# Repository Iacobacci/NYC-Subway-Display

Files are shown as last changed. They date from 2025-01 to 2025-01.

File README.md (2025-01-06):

# NYC Subway Time LED Matrix Display
## Overview

This project was derived from https://github.com/techytobias/NYC-Subway-Display/. Changes to this version:
- Displays 4 screens on a loop related to trains at 34th st Herald Square: BDFM Uptown, BDFM Downtown, NQRW Uptown, NQRW Downtown.
- Removal of the disruptions screen.
- The MTA no longer requires API keys to access the subway feed.
- Utilizes a Raspberry Pi Zero W with no driver (underpowered for this project, likely causing the screen flickering).
- Inclusion of Fusion 360 files for enclosure

#### Capabilities
- Display times for arriving uptown and downtown trains at any NYC subway station
- Rotate through time displays for multiple stations

Demo:


Front of Display
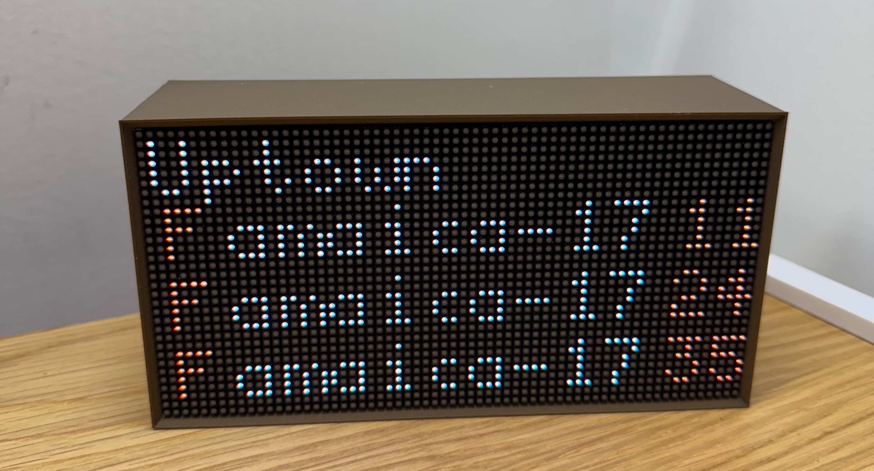
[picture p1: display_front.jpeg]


Back of Display
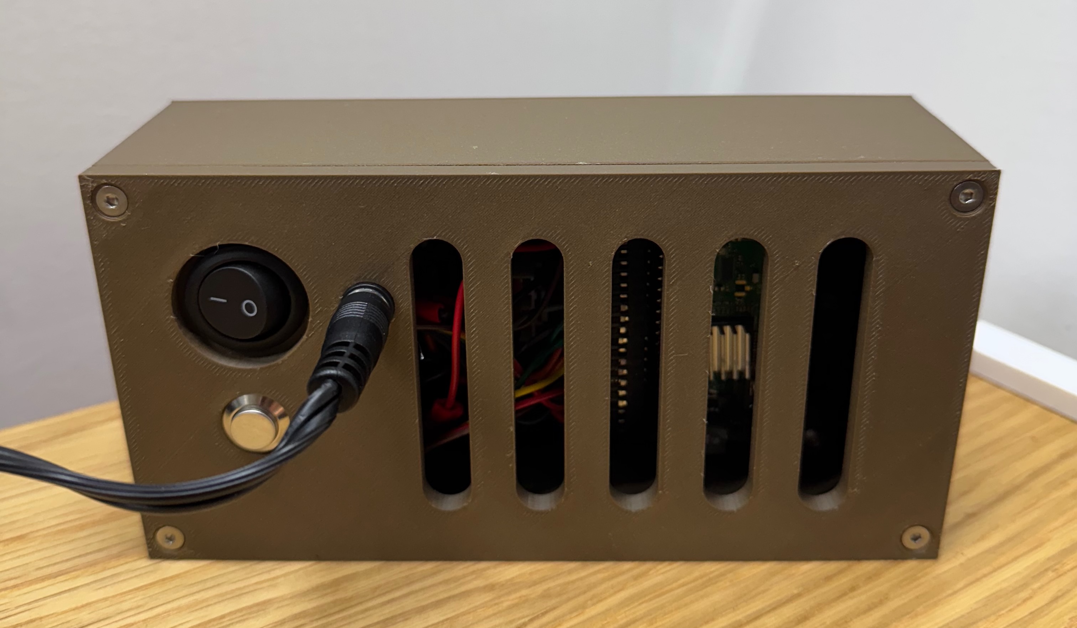
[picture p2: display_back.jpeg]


Display Internals
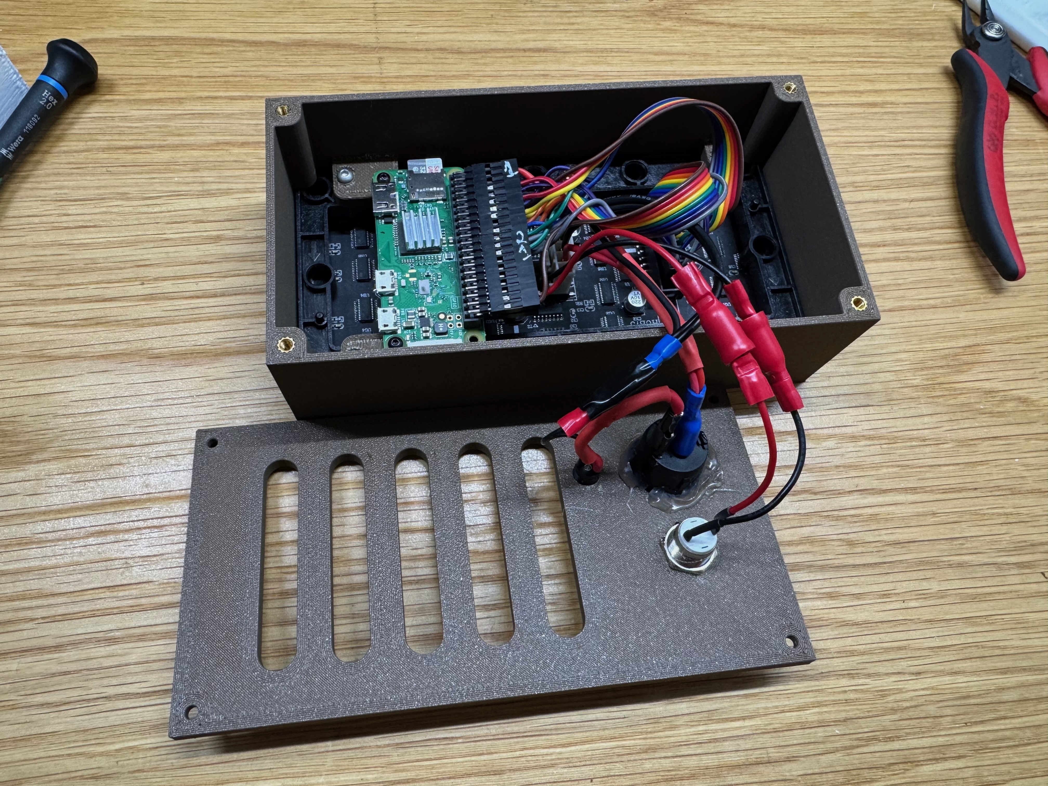
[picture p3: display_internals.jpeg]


## Materials
- Raspberry Pi Zero W (again, unpowered for this application)
- SD Card (8GB Class 10 or better)
- LED Matrix. I used [this Adafruit one, which is 64 x 32 with a 2.5mm led spacing](https://www.adafruit.com/product/5036)
- Adequate power for the display and Pi -- I used [this adapter](https://www.adafruit.com/product/1466).

## Before You Begin This Guide
- Follow [this setup](https://github.com/hzeller/rpi-rgb-led-matrix/tree/master) guide to get your LED Matrix Panel working. (As far as I can tell, this is the most popular library for these panels).
- Wire up your LED Matrix following that guide depending on your hardware.
- Follow the [Python setup instructions](https://github.com/hzeller/rpi-rgb-led-matrix/tree/master/bindings/python#python-3) as well.
- Install Headless Raspbian with user display and hostname displaypi. Also remember to enable SSH.
    - You can use a different username/hostname, but you may need to modify different aspects of this code.
- Enable SSH
- Don't move onto this project until you have [Demo -D0 completed (the rotating cube)](https://github.com/hzeller/rpi-rgb-led-matrix/tree/master?tab=readme-ov-file#lets-do-it).

## Creating the display
- At this point, I'm assuming that you have the rotating cube demo file working. Your file structure should look like /home/display/rpi-rgb-led-matrix/bindings/python/samples/
- We will be keeping this file structure during this guide for the sake of simplicity.
#### Transferring Files
- Move the files rundisplay.py , mtacalls2.py, stops.csv , and packageinst.sh to /home/displau/rpi-rgb-led-matrix/bindings/python/samples/
    - I used scp to move the files over.
#### Installing Python dependencies
- In your SSH window, change directory to our main directory
    - cd /home/display/rpi-rgb-led-matrix/bindings/python/samples/
- Run packageinst.sh (You may need to make the file executable using the command below)
    - sudo chmod +x packageinst.sh
    - sudo ./packageinst.sh
- Check your work. You should see lots of new folders in the /home/display/rpi-rgb-led-matrix/bindings/python/ directory.
### Running the code
- First, make rundisplay.py executable
    - sudo chmod +x rundisplay.py
- Then, run the code (Modify this code as needed for your display).
    - sudo ./rundisplay.py --led-rows=32 --led-cols=64 --led-slowdown-gpio=2 -b=30
- You should see train times appear after a few minutes of the code running. You should see the times appear on your terminal window as they are loaded by the API as well.
- If this works, jump to the customization section. If not, follow the troubleshooting section.

## Troubleshooting
#### Basic Troubleshooting
- Ensure whatever file you are trying to run is executable
    - sudo chmod +x filename.abc
- Ensure all python packages are loaded
- Ensure you entered your API key probably
- Recheck whether you can run the rotating cube demo file

#### More Advanced Troubleshooting
- edit mtacalls.py using nano to add the below line:
    - print(totalstationtimes("A41"))
- then, run mtacalls.py
    - sudo python3 mtacalls.py
- you should see train times print out after a few seconds. If you don't, and you see a python error, search the error on stack exchange.

## Customization
- Use stops.csv to find the code for your desired station(s). Use only the first three letters -- the N and S will be used for the uptown and downtown screens.
    - e.g, 232 for Borough Hall, or A41 for Jay St-Metrotech.
    - Note that the station names for some stations in stops.csv have been shortened to fit better on the display.
    - Ensure to change the data links on line 10 of [mtacalls.py](/mtacalls2.py#10) if your station is not on the B,D,F,M,N,Q,R,W. These subway feed links can be found [here](https://api.mta.info/#/subwayRealTimeFeeds).
- Modify the time filter for how long it takes you to get to your station (change mintoarrival on line 54 of [mtacalls2.py](/mtacalls2.py#54))
- Modify the font - I like the font spleen. Change on line 86 of [rundisplay.py](/rundisplay.py#86)
- Create a cron job to run the program on boot, have a button for soft power down (GPIO 26), and reboot every 24 hours.

## To-Do

While this project is functionally "complete" there are several more improvements that can be made:

- The button for a soft power down (and potentially rebooting every 24 hours) is not fully working in the cron job. While this isn't a must-have, it is a nice-to-have. As cutting power to the pi without shutting it down first can corrupt the SD card. As a workaround, you could ssh in and power down prior to cutting power.
- The LED panel still has some flicker even after adding in the ``--led-no-drop-privs`` flag (which significantly reduced flicker from the original baseline). While some of this is likely caused by the pi zero w's hardware limitations, some of this is also likely caused by inefficient resource utilization and could be optimized.
- There is a long delay after the last times are displayed before it loops again. This could be shortened by optimizing code paths.
- Enclosure improvements: Overall fit and finish could be improved, as well as the rigidity.
- Code cleanup: For example, while this version does not use the disruption code, it is still included.

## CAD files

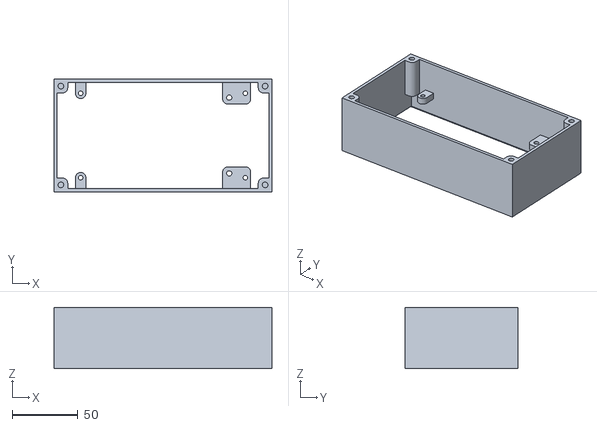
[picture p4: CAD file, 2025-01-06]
cad/LED Panel Middle.obj
165.4 x 85.4 x 46.5

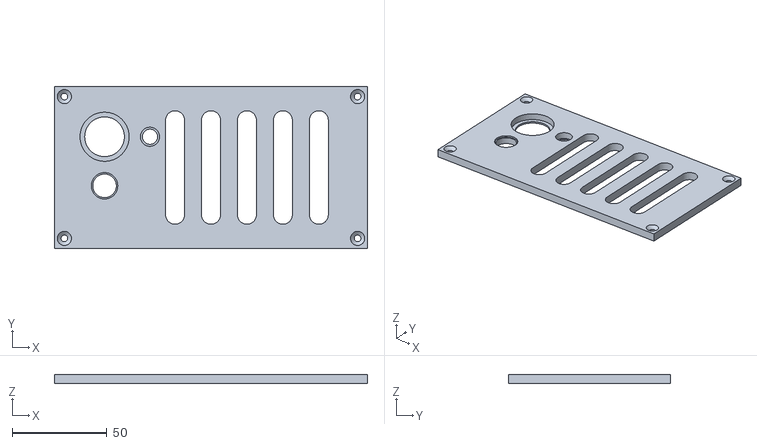
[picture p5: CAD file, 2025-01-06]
cad/LED Panel Back.obj
165.4 x 85.4 x 5.00

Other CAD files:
cad/LED Panel Top.f3d

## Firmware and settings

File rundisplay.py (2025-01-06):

#!/usr/bin/env python
from samplebase import SampleBase
from rgbmatrix import graphics
from subprocess import check_output
import csv
import time
import mtacalls2
import os

script_dir = os.path.dirname(os.path.abspath(__file__))
os.chdir(script_dir)

stops = {}
with open("/home/display/rpi-rgb-led-matrix/bindings/python/samples/stops.csv", 'r') as file:
    csvreader = csv.reader(file)
    header = next(csvreader)
    for row in csvreader:
        stops.update({row[0]: row[1]})

class GraphicsTest(SampleBase):
    def __init__(self, packet, servicedata, *args, **kwargs):
        super(GraphicsTest, self).__init__(*args, **kwargs)
        self.packet = packet
        self.servicedata = servicedata

    def getcolor(self, trainline):
        colors = {
            "4": graphics.Color(0, 146, 66),
            "5": graphics.Color(0, 146, 66),
            "6": graphics.Color(0, 146, 66),
            "1": graphics.Color(255, 0, 0),
            "2": graphics.Color(255, 0, 0),
            "3": graphics.Color(255, 0, 0),
            "A": graphics.Color(0, 57, 163),
            "C": graphics.Color(0, 57, 163),
            "E": graphics.Color(0, 57, 163),
            "B": graphics.Color(255, 99, 32),
            "D": graphics.Color(255, 99, 32),
            "F": graphics.Color(255, 99, 32),
            "M": graphics.Color(255, 99, 32),
            "N": graphics.Color(255, 255, 0),
            "Q": graphics.Color(255, 255, 0),
            "R": graphics.Color(255, 255, 0),
            "W": graphics.Color(255, 255, 0),
            "G": graphics.Color(107, 187, 78),
            "L": graphics.Color(167, 169, 172),
            "7": graphics.Color(185, 52, 170),
            "J": graphics.Color(165, 42, 42),
            "Z": graphics.Color(165, 42, 42)
        }
        return colors.get(trainline, graphics.Color(255, 255, 255))

    def draw_screen(self, canvas, trains, direction, font, scroll_offsets, max_scroll_width):
        canvas.Clear()

        title = "Uptown" if direction == "N" else "Downtown"
        graphics.DrawText(canvas, font, 1, 7, graphics.Color(255, 255, 255), title)

        traincharspacing = 14
        for idx, train in enumerate(trains[:3]):
            color = self.getcolor(train[0])
            train_name = str(train[0])
            stop_name = stops.get(train[2], "Unknown Stop")
            time_to_arrival = str(train[1])

            # Calculate scrolling offset for the stop name
            scroll_offset = scroll_offsets[idx]
            if len(stop_name) > max_scroll_width:
                visible_stop_name = stop_name[scroll_offset:scroll_offset + max_scroll_width]
                scroll_offsets[idx] = (scroll_offset + 1) % (len(stop_name) - max_scroll_width + 1)
            else:
                visible_stop_name = stop_name

            graphics.DrawText(canvas, font, 2, traincharspacing, color, train_name) # Train Line
            graphics.DrawText(canvas, font, 8, traincharspacing, graphics.Color(255, 255, 255), visible_stop_name) # Last Stop
            graphics.DrawText(canvas, font, 55, traincharspacing, color, time_to_arrival)  # Arrival Time

            traincharspacing += 8  # Increment Train Spacing for next train

        self.matrix.SwapOnVSync(canvas)


    def run(self):
        canvas = self.matrix.CreateFrameCanvas()
        font = graphics.Font()
        font.LoadFont("../../../fonts/5x8.bdf")

        max_scroll_width = 9  # Width in characters for stop name display
        scroll_offsets_north = [0, 0, 0]
        scroll_offsets_south = [0, 0, 0]

        for subpacket in self.packet:
            uptown_trains = [train for train in subpacket if train[2][3] == "N"]
            downtown_trains = [train for train in subpacket if train[2][3] == "S"]

            for _ in range(30):
                self.draw_screen(canvas, uptown_trains, "N", font, scroll_offsets_north, max_scroll_width)
                time.sleep(0.4) # Scroll speed

            for _ in range(30):
                self.draw_screen(canvas, downtown_trains, "S", font, scroll_offsets_south, max_scroll_width)
                time.sleep(0.4) # Scroll speed

while True:
    if __name__ == "__main__":
        worked=0
        while worked==0:
            try:
                #D17 is Herald Square BDFM
                #R17 is Herald Square NRQW
                packet=mtacalls2.totalstationtimes(["D17", "R17"])
                servicedata=mtacalls2.procservicedata()
                worked=1
            except:
                print("rebooting in 30 seconds")
                time.sleep(30)
                subprocess.Popen('sudo reboot -n', shell=True)              
        
        graphics_test = GraphicsTest(packet, servicedata)

        if (not graphics_test.process()):
            print("isrunning")

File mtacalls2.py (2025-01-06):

import google.transit
from google.transit import gtfs_realtime_pb2
import requests
import time  # imports module for Epoch/GMT time conversion
import os  # imports package for dotenv
from protobuf_to_dict import protobuf_to_dict
import subprocess

def getdata():
    realtime_data1 = []
    links = [
        "https://api-endpoint.mta.info/Dataservice/mtagtfsfeeds/nyct%2Fgtfs-nqrw",
        "https://api-endpoint.mta.info/Dataservice/mtagtfsfeeds/nyct%2Fgtfs-bdfm"
    ]
    for link in links:
        feed = gtfs_realtime_pb2.FeedMessage()
        response = requests.get(link)
        feed.ParseFromString(response.content)
        subway_feed = protobuf_to_dict(feed)  # subway_feed is a dictionary
        realtime_data = subway_feed['entity']  # train_data is a list
        for element in realtime_data:
            realtime_data1.append(element)
    return realtime_data1


def gettimes(data, station):
    arrivaldata = []
    trainletters = []
    ctimes = station_time_lookup(data, station)
    ctimes.sort(key=lambda row: (row[1], row[0]), reverse=False)
    return ctimes[:6]


def station_time_lookup(train_data, station):
    ctimes = []
    for trains in train_data:  # trains are dictionaries
        if trains.get('trip_update', False) != False:
            unique_train_schedule = trains['trip_update']  # train_schedule is a dictionary with trip 
            try:
                unique_arrival_times = unique_train_schedule['stop_time_update']  # arrival_times is a list of arrivals
                for scheduled_arrivals in unique_arrival_times:  # arrivals are dictionaries with time data and stop_ids
                    if scheduled_arrivals.get('stop_id', False) == station:
                        s1 = unique_train_schedule
                        trainletter = s1['trip']['route_id']

                        test5 = unique_arrival_times[-1]
                        stop = test5['stop_id']

                        time_data = scheduled_arrivals['arrival']
                        unique_time = time_data['time']
                        
                        if unique_time != None:
                            mintoarrival = int(((unique_time - int(time.time())) / 60))
                            if mintoarrival > 2:  # Only displays trains 3 or more mins away
                                ctimes.append([trainletter, mintoarrival, stop])
            except:
                pass
    return ctimes

def totalstationtimes(stationlist):
    finaldata = []
    try:
        data = getdata()
    except:
        print("datafail")
        time.sleep(30)
        subprocess.Popen('sudo reboot -n', shell=True)
    print("datagot")
    for station in stationlist:
        stations = [(station + "N"), (station + "S")]
        newdata = []
        for station1 in stations:
            arrd = gettimes(data, station1)
            for element in arrd:
                newdata.append(element)
        newdata.sort(key=lambda row: (row[1], row[0]), reverse=False)
        finaldata.append(newdata)
    return finaldata

def getservicedata():
    realtime_data1 = []
    links = ["https://api-endpoint.mta.info/Dataservice/mtagtfsfeeds/camsys%2Fsubway-alerts"]
    for link in links:
        feed = gtfs_realtime_pb2.FeedMessage()
        response = requests.get(link)
        feed.ParseFromString(response.content)
        subway_feed = protobuf_to_dict(feed)  # subway_feed is a dictionary
        realtime_data = subway_feed['entity']  # train_data is a list
        for element in realtime_data:
            realtime_data1.append(element)
    return realtime_data1


def procservicedata():
    problemtrains = []
    mainlist = getservicedata()[:10]
    mainlist2 = []
    for element in mainlist:
        if element["id"][4] == "a":  # separates active alerts from planned service changes
            mainlist2.append(element["alert"]["informed_entity"])

    for element4 in mainlist2:
        for element5 in element4:
            try:
                if element5["route_id"] not in problemtrains:
                    if "S" not in element5["route_id"]:
                        problemtrains.append(element5["route_id"])
            except:
                pass
    if len(problemtrains) == 0:
        problemtrains = ["None"]
    problemtrains.sort()
    return problemtrains

# Example usage
#print(totalstationtimes(["232", "A41"]))
#print(procservicedata())
